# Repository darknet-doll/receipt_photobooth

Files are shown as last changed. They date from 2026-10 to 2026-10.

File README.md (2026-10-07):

# Receipt Photobooth

A Raspberry Pi 5 photobooth that prints on a thermal receipt printer. Guests tap the touchscreen, take
three photos, and walk away with a receipt-tape keepsake.

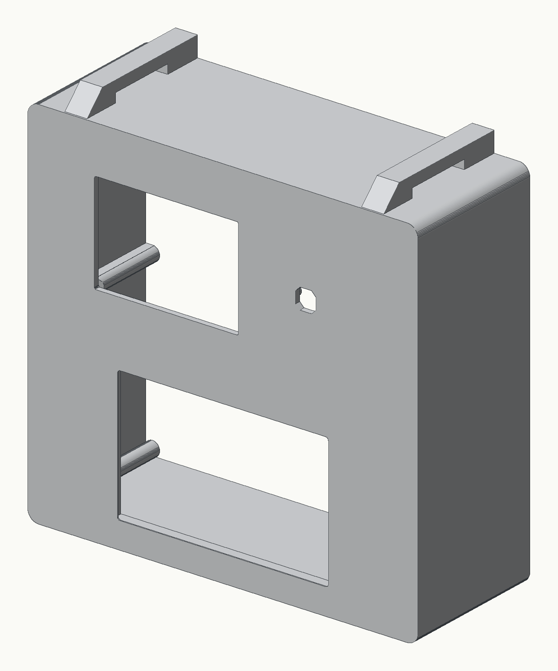
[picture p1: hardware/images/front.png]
The enclosure, front


This repo has everything to build one:

| Folder | What's in it |
|---|---|
| [`hardware/`](hardware/) | STL and 3MF files for the plain enclosure, the parts list, and how it goes together |
| [`software/`](software/) | the booth app (Python), the Pi setup, and a simulator that runs it on a laptop |
| [`docs/`](docs/) | the **Tape Bench**, a browser designer for the receipt (also live at the link below) |
| `sets/` | example receipt designs saved from the Tape Bench |

## Design a receipt in the browser

**https://darknet-doll.github.io/receipt_photobooth/**

A dot-for-dot simulator of the printer: 384 dots a line, 8 dots a millimetre, 48 mm of ink on 57 mm paper.
Change the shop name, the lines under each photo, the rules, the totals and the type sizes; the preview
redraws as you type. When you like it, press **Download receipt.json** and copy that file to
`~/photobooth/receipt.json` on your booth. The booth re-reads it at the start of every session, so there is
no restart.

The character palette on the left is every glyph the printer can actually print. A dashed box marked
**16** means that glyph goes faint at the small text size, so use it on a bigger line.

## Build one

1. **Parts:** see the parts list in [`hardware/README.md`](hardware/README.md). In short: a Raspberry Pi 5,
   a 5" HDMI touchscreen, a Camera Module 3, a 58 mm USB thermal printer and a USB-C power bank.
2. **Print:** the tub, the lid, the Pi bridge plate and two screen sleeves, from `hardware/stl/`.
3. **Assemble:** follow [`hardware/README.md`](hardware/README.md).
4. **Software:** follow [`software/README.md`](software/README.md). Flash Raspberry Pi OS, copy `software/`
   over, run one install script, and tap the Photobooth icon.

You don't need any hardware to try it: `software/tools/simulate.sh` runs the real booth UI in a window on
a Mac or PC, with a synthetic camera and the receipt saved as a PNG.

## Licence

- Code (`software/`, `docs/`): [MIT](LICENSE)
- Enclosure models (`hardware/`): [CC BY-NC 4.0](hardware/LICENSE). Build your own and remix it, but don't
  sell the enclosure.

Made by darknetdoll.

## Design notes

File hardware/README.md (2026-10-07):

# Hardware

A two-part printed enclosure: a **tub** (the front face with the walls grown off its back) and a flat **lid**
that screws on the back. Inside, the screen bolts into the face, a **Pi bridge plate** bolts over the screen,
and the Pi rides on that plate. The power bank lies flat behind the screen.

| Front | Exploded, from the back |
|---|---|
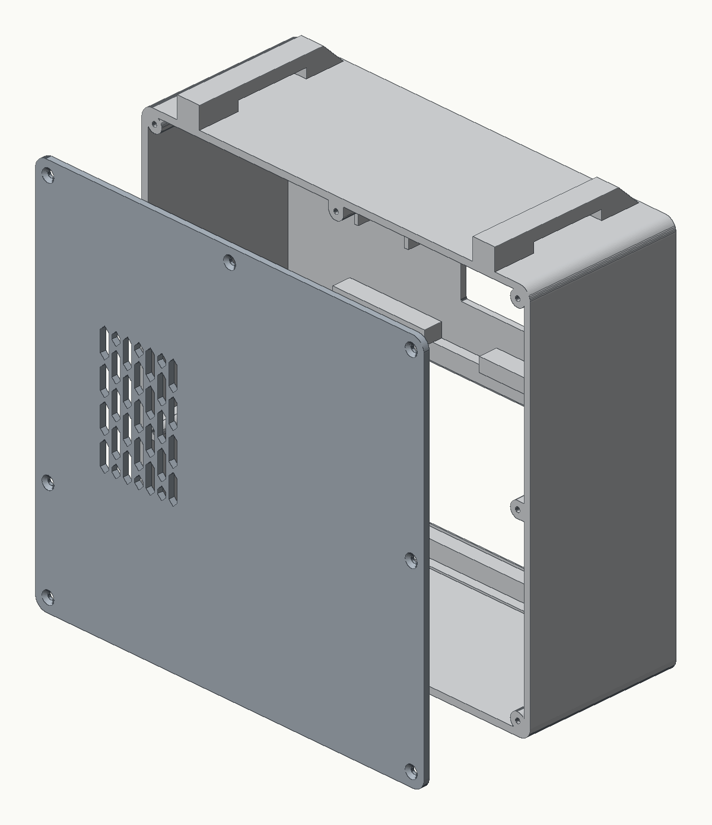
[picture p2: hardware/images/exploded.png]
exploded
| front |  |

Outside size: 211.8 × 210.5 × 82.5 mm (width × height including the two strap loops on top × depth with the lid).

## Parts list

| Part | Notes |
|---|---|
| Raspberry Pi 5, 4 GB | with the active cooler, a microSD card and a micro-HDMI to HDMI cable |
| ELECROW 5" HDMI touchscreen, 800 × 480 (model RC050S) | HDMI for video and micro-USB for touch + power. It is not a DSI screen. The face is sized for this exact board. |
| Camera Module 3 (Arducam's version) | with a 15-to-22-pin CSI cable for the Pi 5. The face's camera posts are measured from the Arducam board; the official Raspberry Pi board has its holes in slightly different places. |
| Tiny thermal receipt printer, CSN-A4L, USB | panel-mount, identifies itself as a **Gprinter GP-58**, ESC/POS, 384 dots per line. Its two wedge clips hold it in the face. |
| 57 mm thermal paper | rolls up to 30 mm across |
| USB-C power bank, about 155 × 54 × 50 mm max | built around a UGREEN Nexode 25000. It needs a USB-C PD port for the Pi and a USB-A port for the printer. |
| USB-A to 2-wire lead for the printer's power | the printer needs its own 5 V, at least 1.5 A while printing. **Do not power it from the Pi.** |
| Optional: SK6812 **RGBW** LED strip | see [LED strip](#optional-led-strip) |

### Screws

| Joint | Screw | Qty |
|---|---|---|
| Screen, lower ears, into the face | M3 × 8 | 2 |
| Screen, upper ears, through the bridge bar and a sleeve | M3 × 16 | 2 |
| Bridge plate into the two bosses on the face | M3 × 12 | 2 |
| Pi onto the bridge plate | M2.3 × 5 | 4 |
| Camera onto its posts | M2 × 5 or M2.3 × 5 | 4 |
| Lid onto the tub | M3 × 10 countersunk | 6 |

Every screw is self-tapping into a printed pilot hole. There are no heat-set inserts or nuts.

## Printing

| File (`stl/` or `3mf/`) | Orientation | Supports |
|---|---|---|
| `tub` | face down on the bed | none: the hanging bosses and the strap loops are chamfered at 45° |
| `lid` | outer face down | none |
| `pi_bridge_plate` | plate flat, bosses up; the two screen sleeves are included beside it | none |
| `screen_sleeves` | the same two Ø8 × 6 mm sleeves on their own, standing, if you need spares | none |
| `test_corner_coupon` | as exported | none |

**Print the test corner coupon first.** It is one corner of the tub and the lid, with the lid fit and the
screw pilots. It takes a fraction of the tub's print time and tells you whether your printer's tolerances
suit the parts before you commit to the big print. The prototype was printed in PETG.

The 3MF files are the same parts in print orientation. Bambu Studio and PrusaSlicer open them directly.

## Assembly

All of this happens from the back, with the tub lying face down.

1. **Printer.** Push it into the larger cutout from the front and clamp it from behind with its two wedge
   clips. The face is 3 mm thick; the clips take 0 to 3.9 mm.
2. **Camera.** Put it on the four posts behind the small octagonal window with M2 × 5 screws, cable edge pointing down.
3. **Screen.** Drop it into the pocket in the lower half, HDMI edge toward the printer. Screw its two lower
   ears down with M3 × 8.
4. **Bridge plate.** Stand a sleeve on each of the screen's upper ears. Lay the bridge plate over them so its
   bar runs across the top of the screen and its top end sits on the two bosses near the top wall. Put M3 × 16
   through the bar and the sleeves into the upper ears, and M3 × 12 through the plate's top holes into the bosses.
5. **Pi.** Stand it on end on the plate's four bosses, USB ports up, with M2.3 × 5. Its port edge faces the side
   wall that has no middle boss, which is the space left free for the plugs.
6. **Camera cable.** Run it down from the camera, under the plate, round the plate's edge and into **CAM0**.
7. **Cables.** Run micro-HDMI from the Pi to the screen's HDMI. Run USB from the Pi to the screen's
   touch + power micro-USB (not the power-only one). Run USB from the Pi to the printer's data port.
8. **Power.** Lay the bank flat behind the screen along the bottom wall. Its USB-C port powers the Pi, and its
   USB-A port powers the printer through the 2-wire lead.
9. **Lid.** Close it with six M3 × 10 countersunk screws. The vent slots go over the Pi's cooler.

The two loops on the top wall take a carry strap.

```text
power bank USB-C  -> Raspberry Pi 5 (which powers the screen, touch and camera)
power bank USB-A  -> printer power (2-wire lead)
Pi micro-HDMI     -> screen HDMI
Pi USB            -> screen touch micro-USB
Pi USB            -> printer data   (it shows up as /dev/usb/lp0)
camera            -> CSI cable -> CAM0
```

The Pi bridge plate on its own:

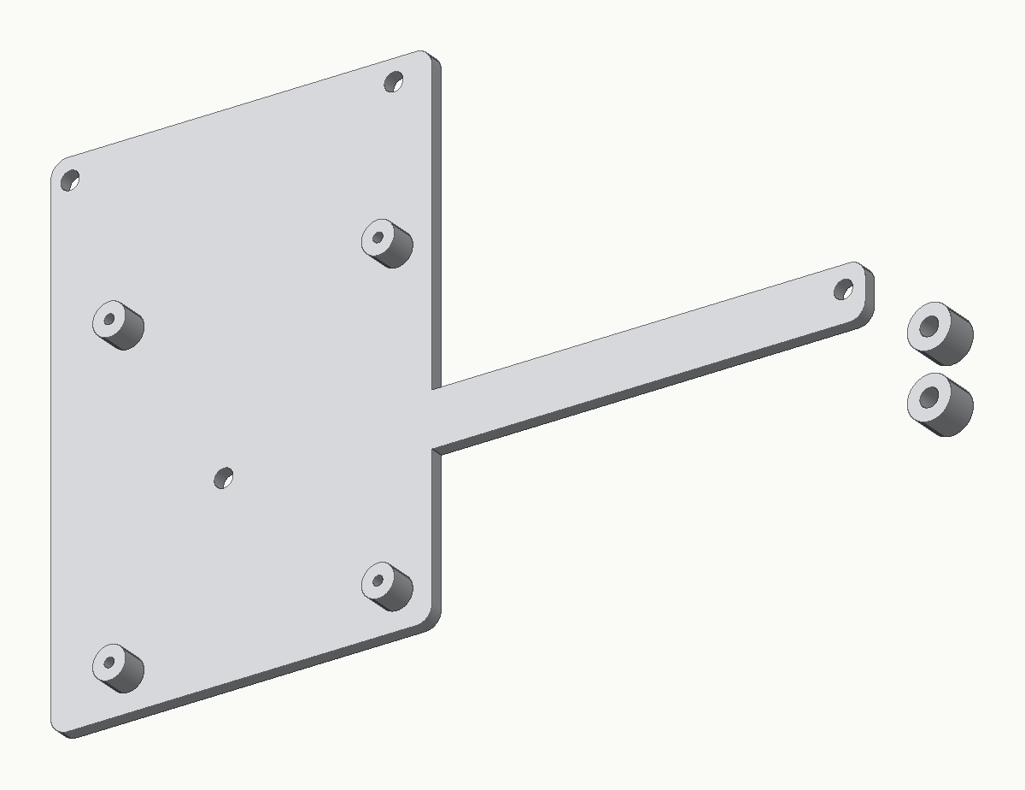
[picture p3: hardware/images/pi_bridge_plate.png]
Pi bridge plate


## Optional: LED strip

The software drives an SK6812 **RGBW** strip (4 bytes a pixel, colour order GRBW) on GPIO10, physical pin 19,
and shows idle, capture and printing light cues. Without a strip it does nothing.

```text
strip +5V  -> its own 5 V supply, never the Pi's 5 V pins
strip GND  -> that supply's minus AND a Pi GND pin (pin 20), run alongside the data wire
strip DIN  -> GPIO10 (pin 19) through a 330-470 ohm resistor, under 20 cm
```

**Tie the grounds together.** If the Pi's ground and the strip supply's ground aren't joined, the data
line floats. You get wrong colours, frozen frames and random flicker, and it looks like every other fault.
Check with a meter that Pi GND and the supply's minus are a dead short before debugging anything else.
The Pi drives 3.3 V logic into a 5 V part with little margin, so a 74AHCT125 level shifter on the data line
is the robust fix.

Set the strip's pixel count in `software/booth/led.py` (`count`).

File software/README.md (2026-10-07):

# Software

The booth app is Python on a Raspberry Pi 5: a fullscreen pygame UI on the touchscreen, picamera2 for the
camera, and ESC/POS written straight to the thermal printer. It needs no printer driver and no CUPS.

**What a guest sees:** a mirrored live preview and TAP TO START. Then three 3-2-1 countdowns, each with a
flash and a still. The receipt appears with **PRINT** and **CANCEL**; it prints on PRINT, or after 20 s if
the guest walks off. Then "take your receipt!" and back to the start.

Every session is saved on the Pi under `~/photobooth/captures/<timestamp>/`: the photos plus the
receipt PNG.

## Try it on a laptop first

```bash
software/tools/simulate.sh            # Mac or PC: the real UI in a window, synthetic camera
software/tools/simulate.sh --help     # every booth option, plus --photos-dir to use your own pictures
```

The first run makes a private virtualenv (`software/.venv-sim`) with pygame, Pillow and numpy using
[uv](https://docs.astral.sh/uv/). Without uv, run `python3 -m pip install -r software/requirements.txt` and
then `python3 software/tools/simulate.py`. Prints are saved as PNGs under `~/photobooth/sim/`.

## Set up the Pi

Tested on **Raspberry Pi OS Trixie (Debian 13), 64-bit, with the desktop**, Python 3.13. picamera2, pygame,
Pillow and numpy come with the OS image.

1. **Flash** Raspberry Pi OS (64-bit, with desktop) with Raspberry Pi Imager. Set a username, Wi-Fi and SSH
   in the Imager's settings.
2. **Get the code onto the Pi.** Either clone this repo on the Pi, or from your computer on the same network:

   ```bash
   PI=youruser@raspberrypi.local software/tools/deploy.sh
   ```

   `deploy.sh` copies `software/` to `~/photobooth/software` on the Pi and installs the desktop icons.
   After a `git clone`, run `software/tools/install_desktop.sh` on the Pi yourself.
3. **Optional: OpenCV**, only for the face-tracking experiment (`tools/face_booth_sim.py`, which draws squares
   round faces). The booth itself doesn't need it.

   ```bash
   sudo apt install python3-opencv
   ```

4. **Printer access.** The printer appears as `/dev/usb/lp0`, owned by group `lp`. CUPS polls it and briefly
   unplugs it, so turn CUPS off:

   ```bash
   sudo usermod -aG lp $USER          # then log out and back in
   sudo systemctl disable --now cups cups.socket cups.path && sudo systemctl mask cups
   ```

5. **Clock.** Receipts are stamped with the Pi's time. Set your own time zone:
   `sudo raspi-config` → Localisation Options → Timezone.
6. **Check the hardware:**

   ```bash
   cd ~/photobooth/software
   python3 tools/camera_check.py --show 8      # 8 s live preview on the touchscreen, then one still
   python3 tools/printer_check.py              # device check, a line of text and a test pattern
   python3 tools/flicker_check.py              # finds the lamp flicker rate (sets --mains)
   ```

   Over SSH, name the desktop's display first:
   `export WAYLAND_DISPLAY=wayland-0 XDG_RUNTIME_DIR=/run/user/1000`.
7. **Optional LED strip** (see `hardware/README.md` for the wiring):

   ```bash
   pip install --break-system-packages adafruit-blinka-raspberry-pi5-neopixel adafruit-circuitpython-neopixel
   python3 tools/led_check.py --white
   ```

## Run it

Tap the **Photobooth** icon on the Pi's desktop. Or, from SSH or a terminal:

```bash
tools/booth.sh start              # the photobooth (stops any running booth first)
tools/booth.sh stop
tools/booth.sh status             # what is running, camera + printer health
tools/booth.sh log                # follow the current log
tools/booth.sh screen upside-down # rotate the screen (portrait / portrait-flipped / landscape / upside-down)
tools/booth.sh lock               # carry lock for transport: booth stopped, Wi-Fi + Bluetooth off; hold the screen 3 s to unlock
tools/booth.sh radios on          # Wi-Fi + Bluetooth back on (any other booth.sh command does this too)
```

Everything after `start` is passed to the app (`python3 tools/photobooth.py --help` lists it all):

| Option | Effect |
|---|---|
| `--theme receipt` (default) | register-tape receipt, each photo a line item |
| `--theme classic` | a plain titled photo strip |
| `--theme film` | 35 mm film strip with names and date up the rail |
| `--theme stamp` | postage stamps, the date over one and the names over the next |
| `--theme grimoire` | a spellbook cover; the guest picks which of two photos goes in its window |
| `--theme birthday` / `--theme mayhem` | example single-photo receipts |
| `--photos N`, `--countdown S` | photos per session, seconds per countdown |
| `--title TEXT` | the shop name on the receipt |
| `--confirm-timeout S` | auto-print delay on the PRINT/CANCEL screen (default 20; 0 waits for a tap) |
| `--no-print` | save the receipt PNG but don't print (for testing without paper) |
| `--hflip`, `--vflip`, `--no-mirror` | camera mounting and preview mirroring |
| `--mains 60\|50\|0` | hold exposure to the mains flicker period of your lights (60 Hz in North America, 50 Hz in most other countries) |

Keyboard: Space or Enter starts a session, Escape cancels, Q quits.

## Design your own receipt

- **Tape Bench** (in a browser, nothing to install): https://darknet-doll.github.io/receipt_photobooth/.
  Design it, press **Download receipt.json**, and copy the file to `~/photobooth/receipt.json` on the Pi.
- **Receipt Studio** (on the Pi): `tools/booth.sh studio`, then open `http://raspberrypi.local:8765` from any
  device on the network. It previews with your real photos and can send a test print.
- **In code:** every string on the receipt is a field of `ReceiptSettings` in `booth/receipt.py`.

The booth re-reads `~/photobooth/receipt.json` at the start of every session, so changes need no restart.

## What's where

```text
software/
├── booth/                the app
│   ├── app.py            the fullscreen loop: preview, countdown, capture, confirm, print
│   ├── camera.py         picamera2: smooth preview + full-resolution stills, flicker guard
│   ├── printer.py        ESC/POS over /dev/usb/lp0: raster bands, dithering, feed
│   ├── receipt.py        the receipt layout and its presets
│   ├── strip.py, film.py, stamp.py, grimoire.py   the other layouts
│   ├── faces.py          face-tracking squares, YuNet (models/); used by tools/face_booth_sim.py only
│   ├── led.py            LED strip cues
│   ├── cute.py           the UI's look
│   └── sim.py            the fake camera + printer for the simulator
└── tools/                launch, deploy, install and hardware-check scripts
```

## Troubleshooting

- **No `/dev/usb/lp0`:** the printer isn't powered. Its USB cable carries data only; it needs its own 5 V supply.
- **Prints come out blank or faint:** check the paper is in thermal side out, and that the printer gets at least
  1.5 A while printing.
- **Horizontal bands rolling through photos:** set `--mains` to your country's mains frequency.
- **Taps land in the wrong place, or don't register:** in `~/.config/labwc/rc.xml`, set the touch device's
  `mouseEmulation` to `no`, then log out and back in.

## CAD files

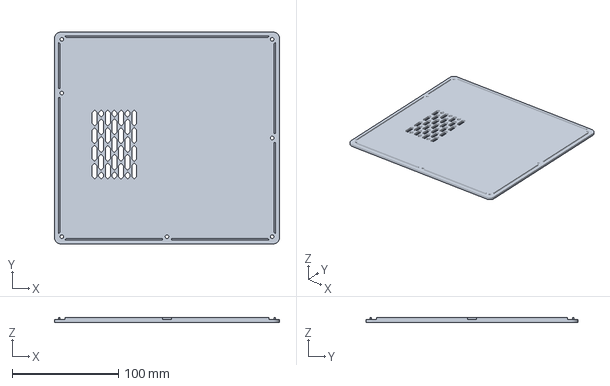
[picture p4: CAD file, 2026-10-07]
hardware/3mf/lid.3mf
211.8 x 199.5 x 5.00 mm

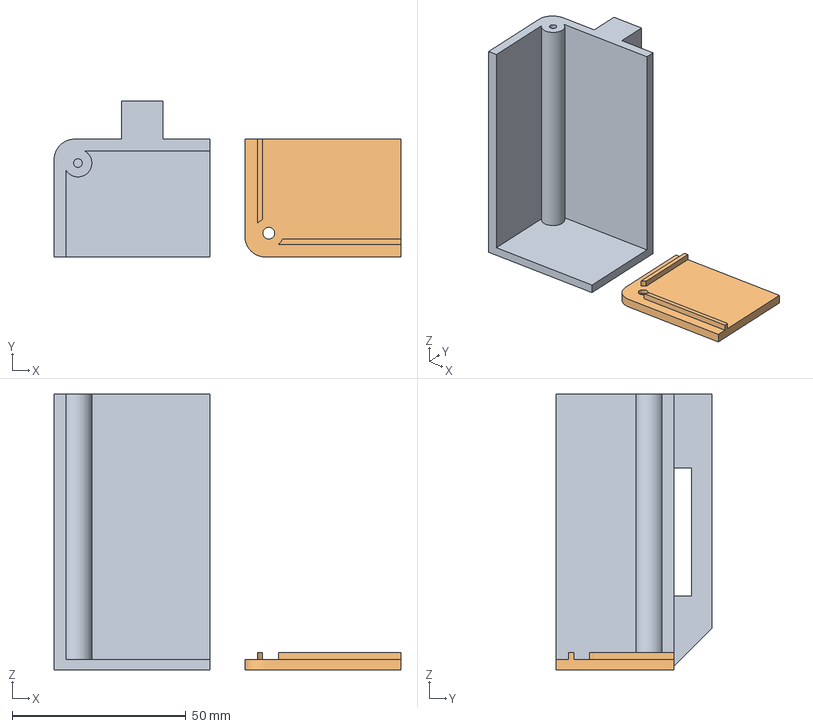
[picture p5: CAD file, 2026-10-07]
hardware/3mf/test_corner_coupon.3mf
100.0 x 45.0 x 79.5 mm
tub corner
lid corner

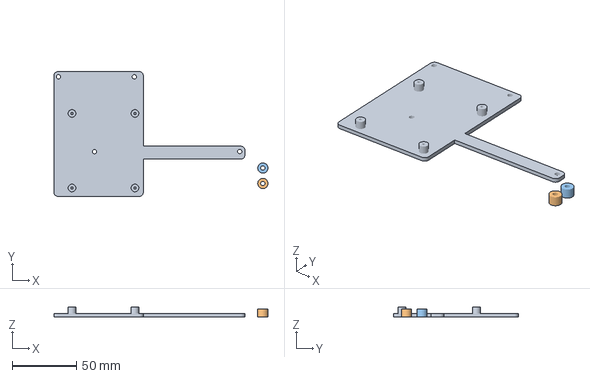
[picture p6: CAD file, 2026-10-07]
hardware/3mf/pi_bridge_plate.3mf
166.5 x 97.0 x 7.50 mm
pi_bridge_plate
spacer_6 x 2

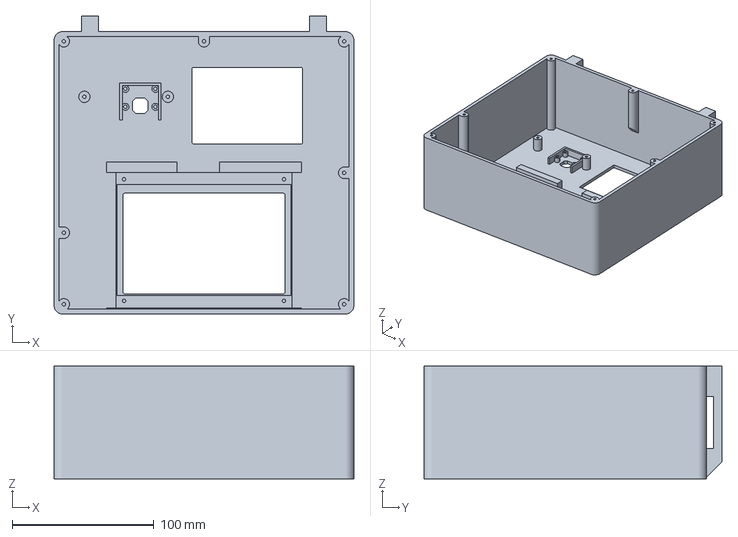
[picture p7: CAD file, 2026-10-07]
hardware/3mf/tub.3mf
211.8 x 210.5 x 79.5 mm

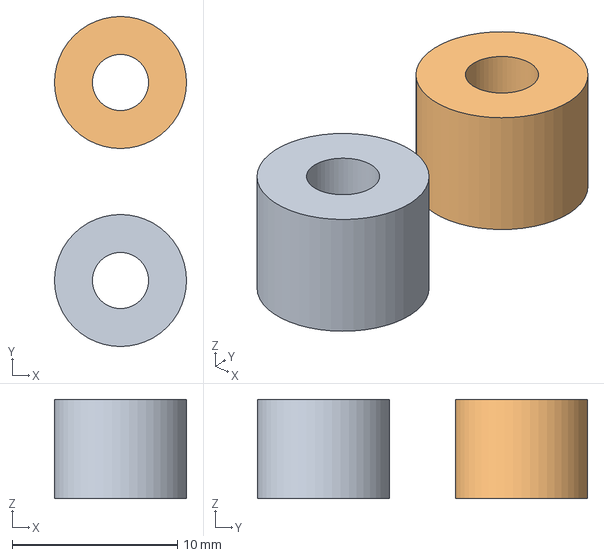
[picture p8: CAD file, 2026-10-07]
hardware/3mf/screen_sleeves.3mf
8.00 x 20.0 x 6.00 mm
sleeve_6 x 2

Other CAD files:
hardware/stl/lid.stl
hardware/stl/pi_bridge_plate.stl
hardware/stl/screen_sleeves.stl
hardware/stl/test_corner_coupon.stl
hardware/stl/tub.stl

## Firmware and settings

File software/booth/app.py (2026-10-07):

"""The photobooth loop: preview -> tap -> countdown -> photos -> receipt -> confirm -> print -> reset.

A small pygame state machine drawn fullscreen on the touchscreen, in landscape
(800x480) or portrait (480x800, ``booth.sh screen portrait``): the layout is
chosen from the screen shape at start-up.

    IDLE       mirrored live preview with a big TAP TO START button
    COUNTDOWN  3-2-1 over the preview, then a white flash and a full-res still,
               repeated for each photo. A CANCEL button aborts the session.
    CONFIRM    the finished receipt on screen with PRINT and CANCEL buttons;
               prints automatically after ``confirm_seconds`` if nobody taps
    REVIEW     the receipt on screen while it prints in a background thread
    DONE       "take your receipt" for a moment, then back to IDLE
    LOCKED     carry-lock, for the bag at a fair: a black screen, input ignored except a
               long press, which shows a "hold to unlock" ring. Armed from IDLE by holding
               the exit corner for ``carry_lock_hold`` seconds (a quick tap there still
               quits, as before) or by ``booth.sh lock`` / the "Carry Lock" desktop icon.

Stills go to ~/photobooth/captures/<session>/, the composed receipt next to them.
Printing failures never stop the loop: the image is still saved and the error is
shown on screen. Cancelling keeps whatever was already saved but prints nothing.

Themes: "receipt" (default, the register-tape design with each photo as a line
item), "birthday" (single-photo Classic Register variant), "mayhem" (the
single-photo Maker Faire tape; it ignores a saved receipt.json, see receipt.PINNED),
"classic" (the plain titled strip from booth/strip.py), "pick" (two photos on
the Maker Faire tape; the guest chooses which photo prints), "grimoire" (two
photos on the framed spellbook cover; the guest chooses which one fills its window),
"duet" (what the desktop icon runs: three photos, then the guest chooses between the
newest receipt sent in from the Tape Bench and the saved film strip).
"""

from __future__ import annotations

import json
import os
import signal
import sys
import threading
import time
from dataclasses import dataclass, replace
from datetime import datetime
from pathlib import Path

if sys.platform.startswith("linux"):            # the Pi desktop is Wayland; leave macOS/Windows alone
    os.environ.setdefault("SDL_VIDEODRIVER", "wayland")

import pygame  # noqa: E402

from . import cute
from .camera import BoothCamera, CameraSettings, CameraTimeout
from .led import BoothLed, LedSettings
from .printer import BoothPrinter, PrinterSettings
from . import tape
from .receipt import (CONFIG_PATH, PINNED, PRESETS, ReceiptSettings, first_photo_bottom,
                      load_choices, load_settings, make_receipt, preset)
from .film import FILM, FilmSettings, make_film_strip
from .grimoire import GRIMOIRE, GrimoireSettings, make_grimoire
from .stamp import PAIR, StampSettings, make_stamp_sheet, sheet_length
from .strip import StripSettings, make_strip, strip_to_screen

CAPTURE_DIR = Path.home() / "photobooth" / "captures"
THEMES = (*PRESETS, "classic", "film", "stamp", "grimoire", "choice", "duet", "pick")
# Themes whose confirm screen offers two LAYOUTS rather than two receipts or two photos: one
# pair each, named here rather than typed into the branches that read them. The pair is what
# varies; everything downstream - the heading, the noun, the photo count, where each side's
# copy comes from - is the same code for both.
CHOICE_PAIRS = {"choice": ("stamp", "film"), "duet": ("receipt", "film")}
# Themes that are not presets themselves but print a preset's copy. Like a pinned preset
# (receipt.PINNED) these never take a saved ~/photobooth/receipt.json: they are not in PRESETS,
# so neither the start-up load nor the per-session reload looks for one.
THEME_PRESET = {"pick": "mayhem"}

# The Sticker Kawaii palette lives in booth/cute.py; these are the roles app.py draws with.
WHITE = cute.WHITE
CREAM = cute.CREAM        # every background that is not a camera frame
INK = cute.INK            # outlines, shadows, body text
PINK = cute.HOT           # the primary action
GREEN = cute.MINT         # PRINT
RED = cute.ALERT          # faults only - cancelling is a quiet cream sticker
CHOOSE_TEXT = "CHOOSE RECEIPT"
CHOOSE_TEXT_CHOICE = "CHOOSE YOUR PRINT"    # a CHOICE_PAIRS theme picks between two layouts
CHOOSE_TEXT_PICK = "CHOOSE YOUR PHOTO"      # one layout over two photos: the picture is the choice
PHOTO_THEMES = ("pick", "grimoire")         # ...which is these two
PAPER_PAD = 8             # cute.paper() inflates its rect by 16, so a card shows 8px above it

# The confirm screen's proportions live in ~/photobooth/ui.json so they can be tuned on the booth
# without editing code or redeploying. Delete the file (or a key) to go back to these numbers.
UI_PATH = Path.home() / "photobooth" / "ui.json"
UI_DEFAULTS = {
    "tape_width": 240,        # how wide each receipt head is drawn - this is the zoom
    "button_height": 86,      # PRINT and START OVER
    "button_width": 0,        # 0 = the width of the words CHOOSE RECEIPT, less button_inset
    "button_inset": 26,       # how much narrower than those words the buttons sit
    "tape_gap": 16,           # space between the two receipts
    "heading_band": 90,       # the strip above the receipts; the heading is centred in it
    "tape_margin": 22,        # gap from the screen edge to a receipt
    "tape_min_width": 170,    # a whole tape narrower than this is cropped to its head instead
}
UI_LIMITS = {"tape_width": (90, 300), "button_height": (52, 150), "button_width": (0, 700),
             "button_inset": (0, 200), "tape_gap": (0, 120), "heading_band": (40, 220),
             "tape_margin": (4, 120), "tape_min_width": (0, 300)}


def load_ui(path: Path = UI_PATH) -> dict:
    """Layout numbers from ~/photobooth/ui.json, falling back per key.

    Anything missing, non-numeric or out of range is ignored rather than raised: a typo in a
    hand-edited file must never stop the booth from opening.
    """
    values = dict(UI_DEFAULTS)
    try:
        with open(path, encoding="utf-8") as fh:
            raw = json.load(fh)
    except (OSError, ValueError):
        return values
    if not isinstance(raw, dict):
        return values
    for key, default in UI_DEFAULTS.items():
        v = raw.get(key)
        lo, hi = UI_LIMITS[key]
        if isinstance(v, (int, float)) and not isinstance(v, bool) and lo <= v <= hi:
            values[key] = int(v)
    return values
GREY = cute.DIM
MILK = cute.MILK          # the card behind the camera window
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

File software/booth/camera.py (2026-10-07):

"""Camera access for the photobooth, built on Picamera2 and libcamera.

Design:

* The sensor runs in its 2304x1296 mode while previewing so the preview stream
  stays smooth (the full 4608x2592 mode only manages ~14 fps).
* Each still is taken with ``switch_mode_and_capture_file`` at full resolution,
  then the camera returns to the preview mode. The mode switch costs well under
  a second, which is fine inside a countdown.
* Autofocus runs continuously during the preview. When a still is requested the
  lens position the preview settled on is locked with ``AfMode.Manual`` for the
  capture, so a failed or hunting focus cycle can never stall the capture.
* Preview frames are returned as RGB numpy arrays (Picamera2 calls this layout
  ``BGR888``), ready for ``pygame.surfarray.make_surface`` or Pillow.
* ``hflip``/``vflip`` describe how the module is physically mounted and apply to
  preview and stills alike. Mirroring the on-screen preview like a mirror is a
  UI concern and is left to the caller (flip the array, not the camera).

Verified on Raspberry Pi 5 / Raspberry Pi OS Trixie with Picamera2 0.3.32 and an
Arducam IMX708 (Camera Module 3 clone) on 2026-09-05.
"""

from __future__ import annotations

import time
from dataclasses import dataclass, field
from pathlib import Path
from typing import Any

import numpy as np

try:
    from libcamera import Transform, controls
    from picamera2 import Picamera2
except ImportError as exc:      # not on a Raspberry Pi; booth/sim.py provides a FakeCamera instead
    Transform = controls = Picamera2 = None  # type: ignore[assignment]
    _IMPORT_ERROR: ImportError | None = exc
else:
    _IMPORT_ERROR = None

FRAME_TIMEOUT = 3.0                # seconds without a frame before CameraTimeout
STILL_TIMEOUT = 10.0
PREVIEW_SIZE = (800, 480)          # matches the ELECROW 5" touchscreen
PREVIEW_SENSOR_MODE = (2304, 1296)  # IMX708 2x2 binned mode, up to 56 fps
CAPTURE_SIZE = (4608, 2592)         # IMX708 full resolution


class CameraTimeout(RuntimeError):
    """The sensor stopped delivering frames (usually a loose CSI ribbon cable)."""


@dataclass
class CameraSettings:
    preview_size: tuple[int, int] = PREVIEW_SIZE
    frame_timeout: float = FRAME_TIMEOUT
    still_timeout: float = STILL_TIMEOUT
    capture_size: tuple[int, int] = CAPTURE_SIZE
    hflip: bool = False
    vflip: bool = False
    autofocus: bool = True
    jpeg_quality: int = 93
    # Period of the room lighting's flicker in microseconds, or 0 to disable.
    # Mains-driven lamps flicker at twice the mains frequency: 8333 for 60 Hz
    # mains (Americas), 10000 for 50 Hz. libcamera's auto-exposure then only
    # picks exposures that are whole multiples of the period, so rolling-shutter
    # bands cannot form. Measured on the bench 2026-09-09: residual banding fell
    # from 11.5 to 0.4 with 8333 under a 60 Hz ceiling lamp.
    flicker_period_us: int = 8333
    # Expose for the person, not the room (added 2026-09-09). A booth subject is
    # always in the middle of the frame, and venues put windows and lamps
    # behind them; with plain averaging a backlit face came out at a quarter
    # of full scale and printed as shadow. CentreWeighted metering biases the
    # AGC to the middle, and the "Shadows" constraint (from the Pi tuning file)
    # stops the darker half of the frame dropping below its floor even if that
    # clips a bright background. Set expose_for_subject=False for plain metering.
    expose_for_subject: bool = True
    # Extra libcamera controls applied while previewing, e.g. {"Sharpness": 1.2}.
    preview_controls: dict[str, Any] = field(default_factory=dict)


class BoothCamera:
    """Thin, photobooth-shaped wrapper around Picamera2."""

    def __init__(self, settings: CameraSettings | None = None) -> None:
        self.settings = settings or CameraSettings()
        self._cam: Picamera2 | None = None
        self._preview_config: dict | None = None
        self._last_metadata: dict = {}

    # -- lifecycle -----------------------------------------------------------

    def start(self) -> None:
        if self._cam is not None:
            return
        if Picamera2 is None:
            raise RuntimeError(f"picamera2 is not available on this machine ({_IMPORT_ERROR}); "
                               "run tools/simulate.py for a fake camera")
        cam = Picamera2()
        transform = Transform(hflip=int(self.settings.hflip), vflip=int(self.settings.vflip))
        self._preview_config = cam.create_preview_configuration(
            main={"size": self.settings.preview_size, "format": "BGR888"},
            raw={"size": PREVIEW_SENSOR_MODE},
            transform=transform,
            buffer_count=4,
        )
        cam.configure(self._preview_config)
        cam.options["quality"] = self.settings.jpeg_quality
        cam.start()
        self._cam = cam
        self._apply_preview_controls()

    def stop(self) -> None:
        if self._cam is None:
            return
        try:
            self._cam.stop()
        finally:
            self._cam.close()
            self._cam = None

    def __enter__(self) -> "BoothCamera":
        self.start()
        return self

    def __exit__(self, *exc: object) -> None:
        self.stop()

    @property
    def cam(self) -> Picamera2:
        if self._cam is None:
            raise RuntimeError("BoothCamera.start() has not been called")
        return self._cam

    @property
    def has_autofocus(self) -> bool:
        return "AfMode" in self.cam.camera_controls

    def _flicker_controls(self) -> dict[str, Any]:
        period = int(self.settings.flicker_period_us)
        if period <= 0:
            return {"AeFlickerMode": controls.AeFlickerModeEnum.Off}
        return {"AeFlickerMode": controls.AeFlickerModeEnum.Manual, "AeFlickerPeriod": period}

    def _exposure_controls(self) -> dict[str, Any]:
        ctrls = self._flicker_controls()
        if self.settings.expose_for_subject:
            ctrls["AeMeteringMode"] = controls.AeMeteringModeEnum.CentreWeighted
            ctrls["AeConstraintMode"] = controls.AeConstraintModeEnum.Shadows
        return ctrls

    def _apply_preview_controls(self) -> None:
        ctrls: dict[str, Any] = dict(self.settings.preview_controls)
        # The still inherits the AGC state the preview converged on, so the
        # subject bias has to run during the preview too, not only on the still.
        ctrls.update(self._exposure_controls())
        if self.settings.autofocus and self.has_autofocus:
            ctrls["AfMode"] = controls.AfModeEnum.Continuous
            ctrls["AfSpeed"] = controls.AfSpeedEnum.Fast
        if ctrls:
            self.cam.set_controls(ctrls)

    # -- preview -------------------------------------------------------------

    def preview_frame(self) -> np.ndarray:
        """Return the newest preview frame as an (H, W, 3) RGB uint8 array.
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
